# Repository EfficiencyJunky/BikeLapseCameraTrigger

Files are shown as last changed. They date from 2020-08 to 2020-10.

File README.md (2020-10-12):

# BikeLapseCameraTrigger Overview

The BikeLapse Camera Trigger is an Arduino based system for using distance (number of wheel rotations on a bike) to trigger a camera shutter release (as opposed to TimeLapse which uses time). It's part of a larger platform called BikeLapse.com that seeks to make it fun and easy to create a virtual catalog of bike rides (or other adventure activities). Plus it's entirely free and open source.

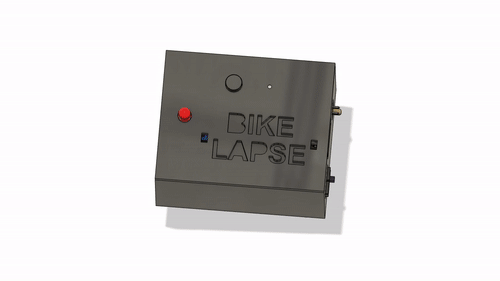
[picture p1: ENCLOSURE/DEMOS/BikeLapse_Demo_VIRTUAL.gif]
BikeLapse Hardware Virtual Demo


This repository is home to everything you should need to build your own BikeLapse Camera Trigger as seen in the animated GIF above and demo videos below. Once you've made the Camera Trigger hardware, visit the BikeLapse.com GitHub repo to learn how to clone the repo (you'll need to modify a couple things of course) and enable your own BikeLapse style website hosted for free on GitHub pages. (it should take less than an hour to get your own instance up and running thanks to the magic of Github).

# DEMOS
Here's a video showing how the BikeLapse camera trigger works and what it is used for
https://www.youtube.com/watch?v=APi-ftsqltU

Here's a demo of a video that was made by stitching together all of the images captured while using the BikeLapse Camera Trigger
https://www.youtube.com/watch?v=EekVvGeG3ls

To see the virtual bike ride version where the video is geo-synchronized to a map...check out https://bikelapse.com

# PROJECT DESCRIPTION AND BUILD INSTRUCTIONS
Visit http://turnerkirk.com/bikelapse for a thorough description of this project and information on how to make your own.

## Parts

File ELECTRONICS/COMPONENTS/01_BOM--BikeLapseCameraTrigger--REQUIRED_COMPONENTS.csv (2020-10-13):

Build Order | Customer Reference | Reference Designator | Quantity | Unit Price | Extended Price | Supplier | Supplier Part Number | Manufacturer | Manufacturer Part Number | Supplier Description | LINK | ALTERNATIVE LINK
0 | MAIN PCB | PCB1 | 1 | $7.77 | $7.77 | OshPark | chaYN0AE | OshPark | chaYN0AE | BikeLapse Camera Trigger MAIN BOARD - V1.3p24 | https://oshpark.com/shared_projects/chaYN0AE
1 | 210 Ohm Resistor for LED | R1 | 1 | $0.10 | $0.10 | Digi-Key | 210XBK-ND | Yageo | MFR-25FBF52-210R | RES 210 OHM 1/4W 1% AXIAL | https://www.digikey.com/en/products/detail/yageo/MFR-25FBF52-210R/12859
3 | Female Headers - Straight | various | 1 | $2.95 | $2.95 | Digi-Key | 1528-2537-ND | Adafruit Industries LLC | 598 | 36-PIN 0.1 FEMALE HEADER- 5PK | https://www.digikey.com/en/products/detail/adafruit-industries-llc/598/8299908 | https://www.adafruit.com/product/598
3 | male headers - Straight | various | 2 | $0.69 | $1.38 | Digi-Key | HDR100IMP40M-G-V-TH-ND | Chip Quik Inc. | HDR100IMP40M-G-V-TH | CONN HEADER VERT 40POS 2.54MM | https://www.digikey.com/en/products/detail/chip-quik-inc/HDR100IMP40M-G-V-TH/5978197
4 | Wheel Sensor (Reed Switch) Connector R/A Headers | S1 | 1 | $0.53 | $0.53 | Digi-Key | 732-2699-ND | Würth Elektronik | 61900211021 | CONN HEADER R/A 2POS 2.54MM | https://www.digikey.com/en/products/detail/w-rth-elektronik/61900211021/2508468
4 | Wheel Sensor (Reed Switch) Connector Housing | S1_external | 1 | $0.13 | $0.13 | Digi-Key | 732-2867-ND | Würth Elektronik | 61900211621 | CONN HSNG 2POS FEMALE 2.54MM | https://www.digikey.com/en/products/detail/w-rth-elektronik/61900211621/2508636
4 | Wheel Sensor (Reed Switch) Connector Receptacle Crimp Pins | S1_external | 3 | $0.10 | $0.30 | Digi-Key | S9473CT-ND | Sullins Connector Solutions | SWT25X-URTC-S01-UU-UU | CONN SOCKET 20-26AWG CRIMP TIN | https://www.digikey.com/en/products/detail/sullins-connector-solutions/SWT25X-URTC-S01-UU-UU/2769670
4 | Wheel Rotation Sensor (Reed Switch) w/ magnet | S1_external | 1 | $15.37 | $15.37 | Planet Bike | SKU #8000-3 | Planet Bike | SKU #8000-3 | PROTEGÉ TANDEM BRACKET - 160CM WIRE | https://www.planetbike.com/protege-tandem-bracket-160cm-wire/ | https://www.amazon.com/dp/B001CJVK9S/
4 | Arduino Bluetooth Brain Board -- NEW | U1 | 1 | $24.95 | $24.95 | Digi-Key | 1528-2828-ND | Adafruit Industries LLC | 4062 | ADAFRUIT FEATHER NRF52840 EXPRES | https://www.digikey.com/en/products/detail/adafruit-industries-llc/4062/9843410 | https://www.adafruit.com/product/4062
4 | BUTTONS PCB | U2_PCB2 | 1 | $1.08 | $1.08 | OshPark | NAQApft2 | OshPark | NAQApft2 | BikeLapse Camera Trigger BUTTON BOARD - V1.3p18 | https://oshpark.com/shared_projects/NAQApft2
4 | 12mm Button - CAMERA_TRIGGER | U2_B1 | 1 | $0.49 | $0.49 | Digi-Key | 430476085716-ND | Würth Elektronik | 430476085716 | SWITCH TACTILE SPST-NO 0.05A 12V | https://www.digikey.com/en/products/detail/w-rth-elektronik/430476085716/5209048
4 | 6mm Button - BLE_RESET | U2_B2 | 1 | $0.40 | $0.40 | Digi-Key | SW406-ND | Omron Electronics Inc-EMC Div | B3F-1070 | SWITCH TACTILE SPST-NO 0.05A 24V | https://www.digikey.com/en/products/detail/omron-electronics-inc-emc-div/B3F-1070/38362
5 | male headers - R/A | J1 | 1 | $0.79 | $0.79 | Digi-Key | HDR100IMP40M-G-RA-TH-ND | Chip Quik Inc. | HDR100IMP40M-G-RA-TH | CONN HEADER R/A 40POS 2.54MM | https://www.digikey.com/en/products/detail/chip-quik-inc/HDR100IMP40M-G-RA-TH/5978204
5 | On/Off Switch Straight | J1 | 1 | $0.65 | $0.65 | Digi-Key | EG1903-ND | E-Switch | EG1218 | SWITCH SLIDE SPDT 200MA 30V | https://www.digikey.com/en/products/detail/e-switch/EG1218/101726
5 | LED 5MM | LED1 | 1 | $0.35 | $0.35 | Digi-Key | 1125-1188-ND | Marktech Optoelectronics | MT4118-HR-A | LED RED DIFFUSED 5MM ROUND T/H | https://www.digikey.com/en/products/detail/marktech-optoelectronics/MT4118-HR-A/4214622
6 | Jumper Shorting Connectors | misc | 2 | $0.10 | $0.20 | Digi-Key | S9337-ND | Sullins Connector Solutions | QPC02SXGN-RC | CONN JUMPER SHORTING .100" GOLD | https://www.digikey.com/en/products/detail/sullins-connector-solutions/QPC02SXGN-RC/2618262
7 | M3 Screw w/ Phillips Head -- 8mm length | hardware | 2 | $0.05 | $4.57 | McMaster-Carr | 92010A118 | McMaster-Carr | 92010A118 | Passivated 18-8 Stainless Steel Phillips Flat Head Screw M3 x 0.5 mm Thread, 8 mm Long | https://www.mcmaster.com/92010A118/
7 | M3 Hex Lock Nut | hardware | 2 | $0.04 | $3.57 | McMaster-Carr | 90576A102 | McMaster-Carr | 90576A102 | Medium-Strength Steel Nylon-Insert Locknut Class 8, Zinc Plated, M3 x 0.5 mm Thread, 4 mm High | https://www.mcmaster.com/90576A102/
8 | 500mah Li-Ion Battery | power | 1 | $7.95 | $7.95 | Digi-Key | 1528-1841-ND | Adafruit Industries LLC | 1578 | BATTERY LITHIUM 3.7V 500MAH | https://www.digikey.com/en/products/detail/adafruit-industries-llc/1578/5054539 | https://www.adafruit.com/product/1578
9 | No6 Thread Cutting Screw w/ Phillips Head -- 1/4" Length | hardware | 4 | $0.05 | $5.02 | McMaster-Carr | 94629A180 | McMaster-Carr | 94629A180 | Thread-Cutting Screws for Plastic 410 Stainless Steel, Number 6 Size, 1/4" Long | https://www.mcmaster.com/94629A180/
9 | M4 Screw w/ Hex Socket Head | hardware | 1 | $0.09 | $9.22 | McMaster-Carr | 91290A148 | McMaster-Carr | 91290A148 | Black-Oxide Alloy Steel Socket Head Screw M4 x 0.7 mm Thread, 12 mm Long | https://www.mcmaster.com/91290A148/
9 | M4 Nut | hardware | 1 | $0.06 | $6.45 | McMaster-Carr | 91828A231 | McMaster-Carr | 91828A231 | 18-8 Stainless Steel Hex Nut M4 x 0.7 mm Thread | https://www.mcmaster.com/91828A231/

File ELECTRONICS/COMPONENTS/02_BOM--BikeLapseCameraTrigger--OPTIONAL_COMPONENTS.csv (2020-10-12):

Build Order | Customer Reference | Reference Designator | Quantity | Unit Price | Extended Price | Supplier | Supplier Part Number | Manufacturer | Manufacturer Part Number | Supplier Description | LINK | ALTERNATIVE LINK
1 (option) | 100k resistor (if using battery with thermistor) | R3 | 1 | $0.10 | $0.10 | Digi-Key | S100KCACT-ND | Stackpole Electronics Inc | RNMF14FTC100K | RES 100K OHM 1/4W 1% AXIAL | https://www.digikey.com/en/products/detail/stackpole-electronics-inc/RNMF14FTC100K/2617434
1 (option) | 120 Ohm Resistor (if using battery with thermistor AND Feather Huzzah ESP8266) | R5 | 1 | $0.10 | $0.10 | Digi-Key | S120CACT-ND | Stackpole Electronics Inc | RNMF14FTC120R | RES 120 OHM 1/4W 1% AXIAL | https://www.digikey.com/en/products/detail/stackpole-electronics-inc/RNMF14FTC120R/2617441
1 (option) | 270 Ohm Resistor (if using battery with thermistor AND Feather Huzzah ESP8266) | R4 | 1 | $0.10 | $0.10 | Digi-Key | S270CACT-ND | Stackpole Electronics Inc | RNMF14FTC270R | RES 270 OHM 1/4W 1% AXIAL | https://www.digikey.com/en/products/detail/stackpole-electronics-inc/RNMF14FTC270R/2617478
4 (option) | Arduino Bluetooth Brain Board -- OLD | U1 | 1 | $24.95 | $24.95 | Digi-Key | 1528-2095-ND | Adafruit Industries LLC | 3406 | FEATHER NRF52 BLUEFRUIT LE - NRF | https://www.digikey.com/en/products/detail/adafruit-industries-llc/3406/7034992 | https://www.adafruit.com/product/3406
5 (future) | On/Off Switch R/A (PCB design currently doesn't accomodate this part) | J1 | 1 | $1.09 | $1.09 | Digi-Key | 563-1555-ND | Nidec Copal Electronics | MFS101D-6-Z | SWITCH SLIDE SPDT 300MA 10V | https://www.digikey.com/en/products/detail/nidec-copal-electronics/MFS101D-6-Z/5086545
8 (alternative) | 1200mah Li-Ion Battery | power | 1 | $9.95 | $9.95 | Digi-Key | 1528-1838-ND | Adafruit Industries LLC | 258 | BATTERY LITHIUM 3.7V 1.2AH | https://www.digikey.com/en/products/detail/adafruit-industries-llc/258/5054544 | https://www.adafruit.com/product/258
8 (alternative) | 1000mah Li-Ion Battery | power | 1 | $9.95 | $9.95 | Digi-Key | 1568-1492-ND | SparkFun Electronics | PRT-13813 | BATTERY LITHIUM 3.7V 1AH | https://www.digikey.com/en/products/detail/sparkfun-electronics/PRT-13813/6605198 | https://www.sparkfun.com/products/13813

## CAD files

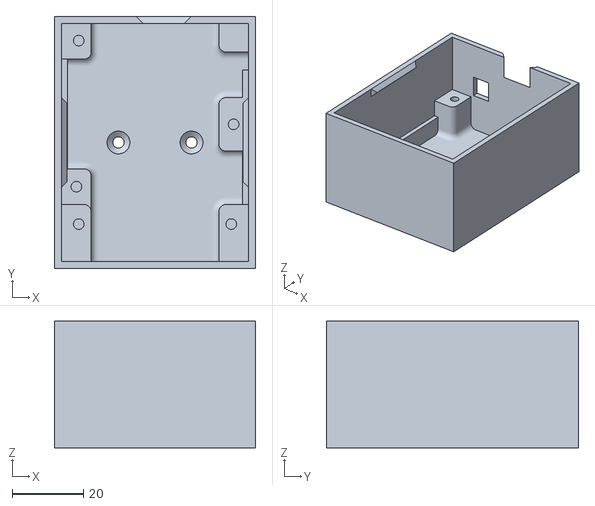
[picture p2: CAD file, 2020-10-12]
ENCLOSURE/3D_MODELS/COMPONENTS--V3p20/BikeLapseTrigger_Enclosure_V3p20--COMP-MAIN.stl
56.4 x 70.8 x 35.6

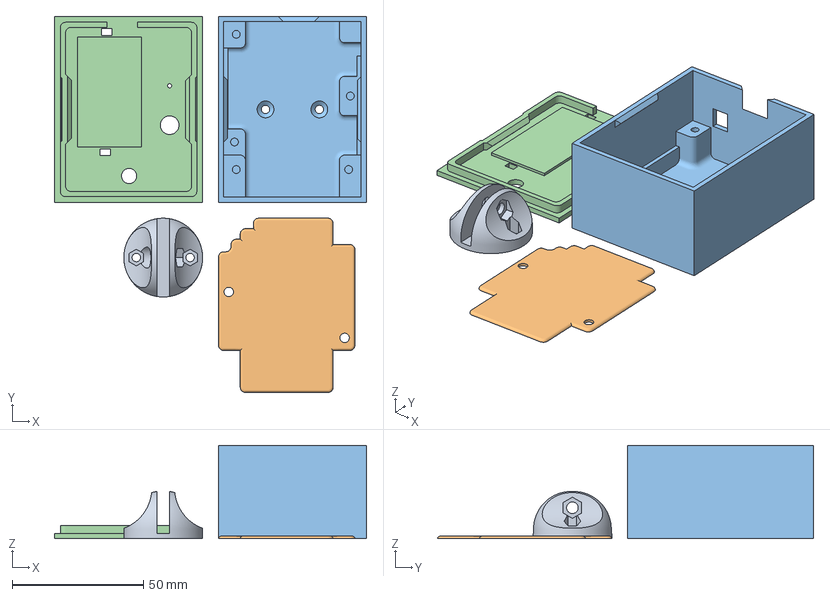
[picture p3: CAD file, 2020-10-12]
ENCLOSURE/3D_MODELS/BikeLapseTrigger_Enclosure_V3p20.3mf
118.8 x 143.2 x 35.6 mm
BikeLapseTrigger_V3p20--COMP-BASE.stl
BikeLapseTrigger_V3p20--COMP-BATT_COVER.stl
BikeLapseTrigger_V3p20--COMP-MAIN.stl
BikeLapseTrigger_V3p20--COMP-TOP.stl

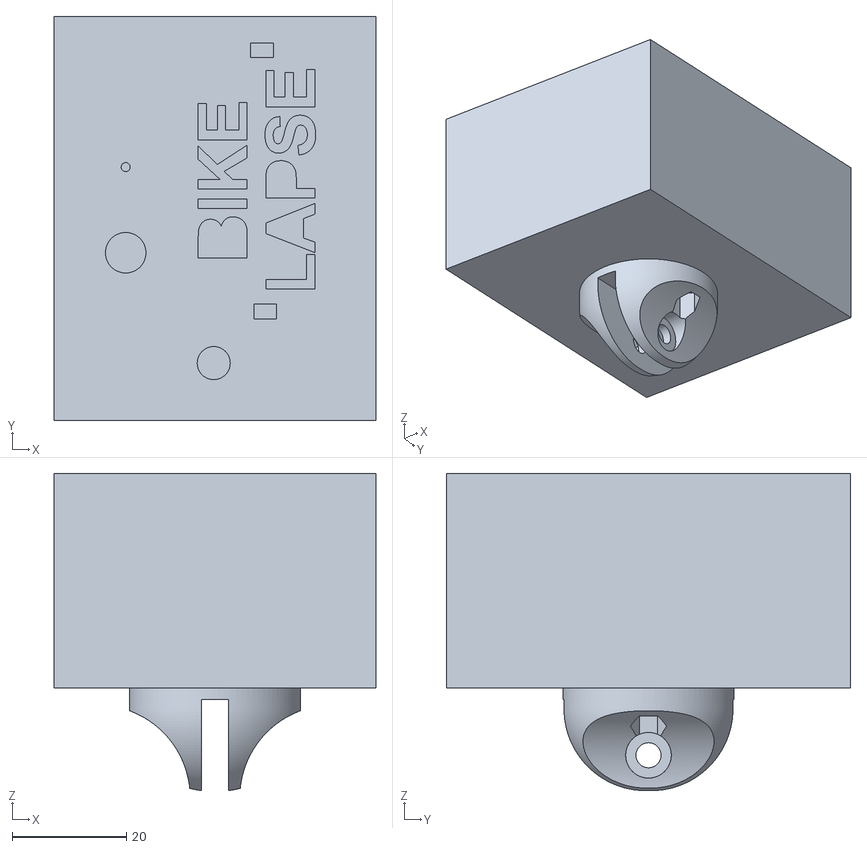
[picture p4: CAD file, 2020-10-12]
ENCLOSURE/3D_MODELS/BikeLapseTrigger_Enclosure_V3p20--SINGLE_FILE.stl
56.4 x 70.8 x 55.6

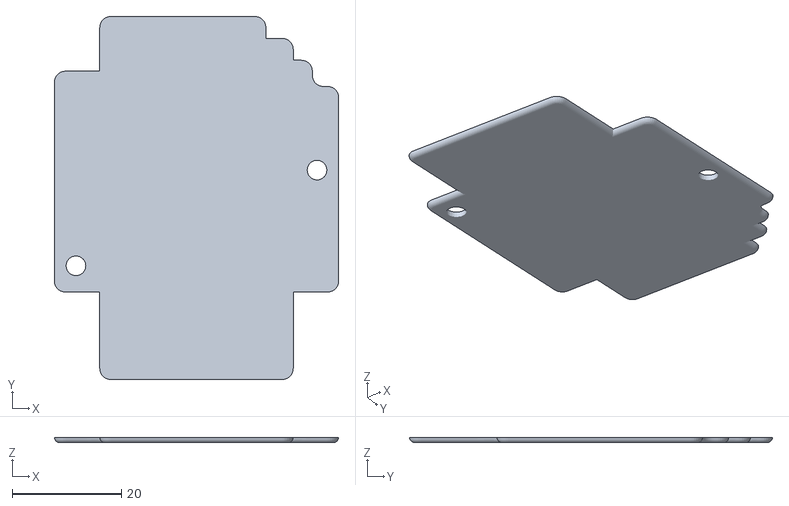
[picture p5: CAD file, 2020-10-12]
ENCLOSURE/3D_MODELS/COMPONENTS--V3p20/BikeLapseTrigger_Enclosure_V3p20--COMP-BATT_COVER.stl
52.0 x 66.4 x 1.00

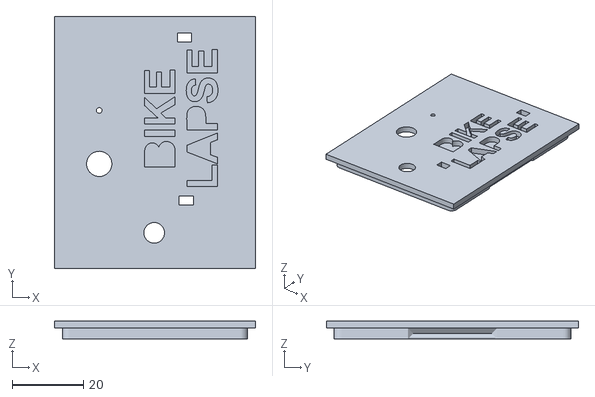
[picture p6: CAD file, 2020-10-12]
ENCLOSURE/3D_MODELS/COMPONENTS--V3p20/BikeLapseTrigger_Enclosure_V3p20--COMP-TOP.stl
56.4 x 70.8 x 5.00

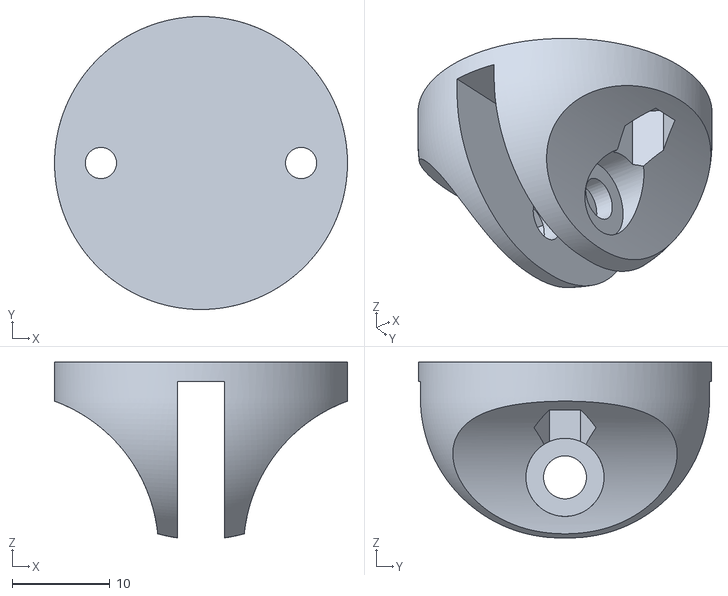
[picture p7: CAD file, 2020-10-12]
ENCLOSURE/3D_MODELS/COMPONENTS--V3p20/BikeLapseTrigger_Enclosure_V3p20--COMP-BASE.stl
30.0 x 30.0 x 18.0

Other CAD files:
ENCLOSURE/3D_MODELS/BikeLapseTrigger_Enclosure_V3p20--BUILD_PLATE.stl
ELECTRONICS/PCB/Button PCB for BikeLapse Camera Trigger v21.f3z

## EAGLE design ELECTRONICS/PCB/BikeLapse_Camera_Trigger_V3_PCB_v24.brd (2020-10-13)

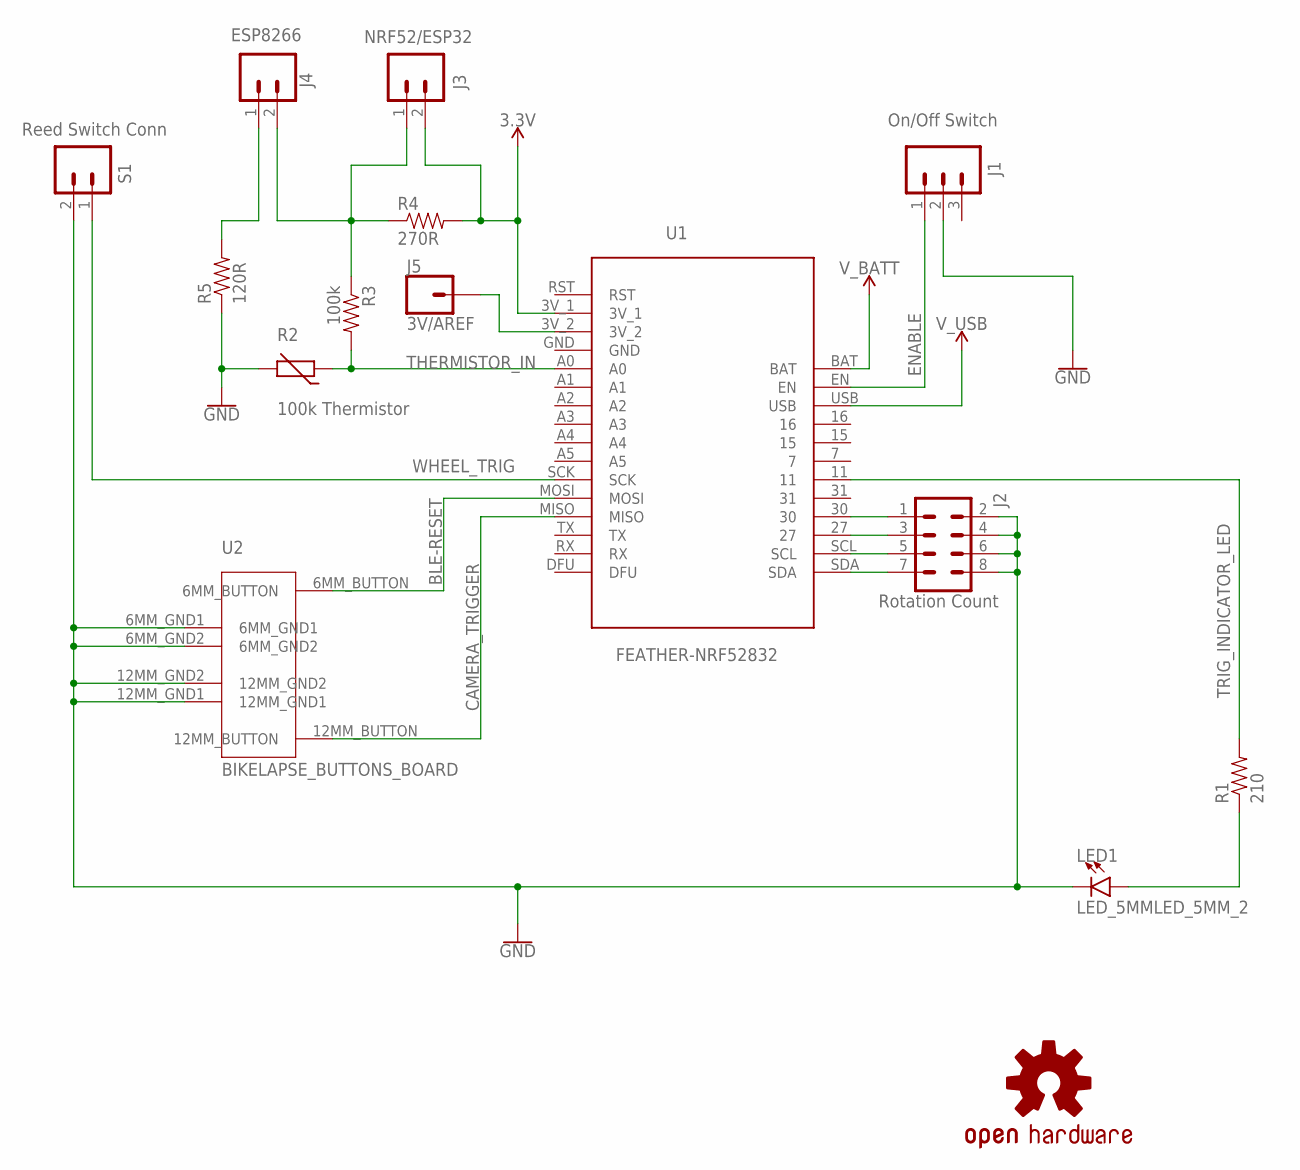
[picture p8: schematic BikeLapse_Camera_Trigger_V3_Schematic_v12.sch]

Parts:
J1: On/Off Switch; 1X03_RA_PTH
J2: Rotation Count; 2X4
J3: NRF52/ESP32; 1X02
J4: ESP8266; 1X02
J5: 3V/AREF; 1X01
LED1: LED_5MMLED_5MM_2; LEDRD254W60D565H860B
LOGO1: OSHW-LOGOL; OSHW-LOGO-L
R1: 210; SPARKFUN-RESISTORS_AXIAL-0.4
R2: 100k Thermistor; RS-2,5-SINGLE_PIN
R3: 100k; SPARKFUN-RESISTORS_AXIAL-0.4
R4: 270R; SPARKFUN-RESISTORS_AXIAL-0.4
R5: 120R; SPARKFUN-RESISTORS_AXIAL-0.4
S1: Reed Switch Conn; 1X02_RA_PTH
U1: FEATHER-NRF52832
U2: BIKELAPSE_BUTTONS_BOARD

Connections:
3.3V: J3.2, R4.P$2 (2), U1.3V_1
BLE-RESET: U1.MOSI, U2.6MM_BUTTON
CAMERA_TRIGGER: U1.MISO, U2.12MM_BUTTON
ENABLE: J1.1, U1.EN
GND: J1.2, J2.2, J2.4, J2.6, J2.8, LED1.K (C), R2.2, R5.P$1 (1), S1.2, U1.GND, U2.6MM_GND1, U2.6MM_GND2, U2.12MM_GND1, U2.12MM_GND2
unnamed: J2.3, U1.27
unnamed: J2.1, U1.30
unnamed: J2.5, U1.SCL
unnamed: J2.7, U1.SDA
unnamed: J5.1, U1.3V_2
unnamed: J4.1, R5.P$2 (2)
unnamed: J3.1, J4.2, R3.P$1 (1), R4.P$1 (1)
unnamed: LED1.A, R1.P$1 (1)
THERMISTOR_IN: R2.1, R3.P$2 (2), U1.A0
TRIG_INDICATOR_LED: R1.P$2 (2), U1.11
V_BATT: U1.BAT
V_USB: U1.USB
WHEEL_TRIG: S1.1, U1.SCK

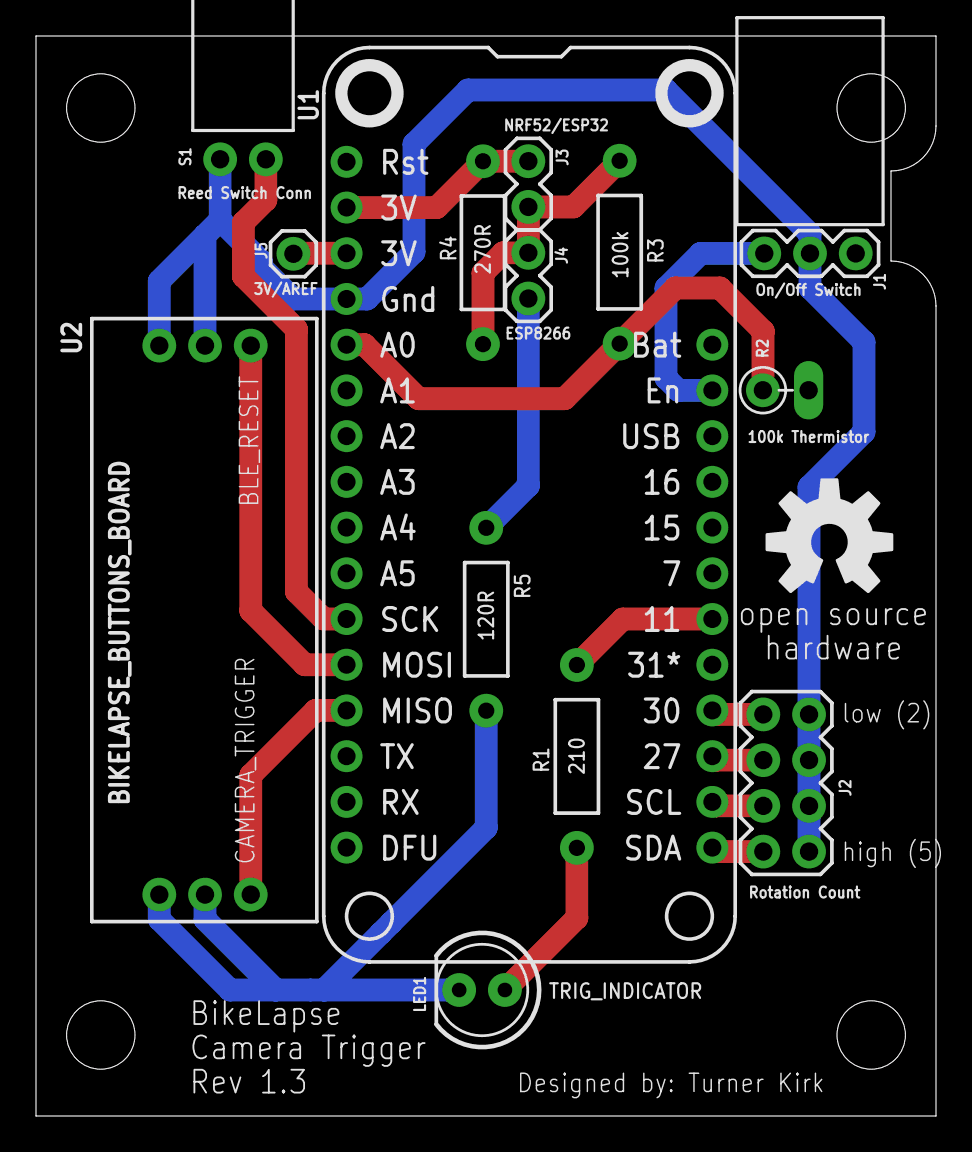
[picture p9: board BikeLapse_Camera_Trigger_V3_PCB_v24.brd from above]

Board: 2 copper layers, 50.0 x 60.0 mm, 15 parts (0 on the bottom side), 16 nets.

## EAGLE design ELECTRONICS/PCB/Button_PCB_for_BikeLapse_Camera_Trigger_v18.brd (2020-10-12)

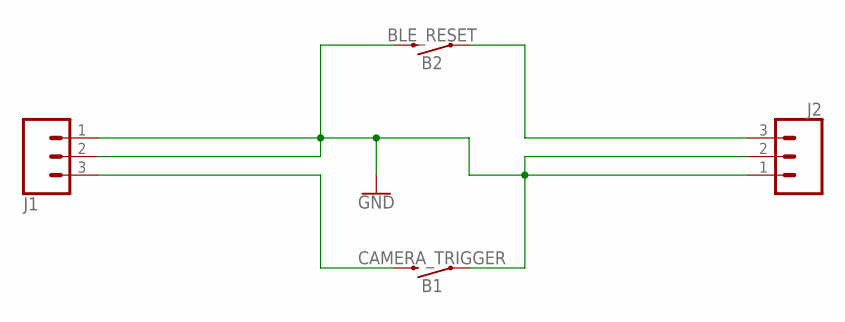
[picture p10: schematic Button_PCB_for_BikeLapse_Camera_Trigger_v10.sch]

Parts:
B1: CAMERA_TRIGGER; TACTILE_SWITCH_PTH_12MM
B2: BLE_RESET; TACTILE_SWITCH_PTH_6.0MM
J1, J2: 455-1750-1-ND; 1X03-MALE_HEADERS_BOTTOM

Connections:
GND: B1.1, B2.3 (2), J1.1, J1.2, J2.1, J2.2
unnamed: B2.1, J2.3
unnamed: B1.3 (2), J1.3

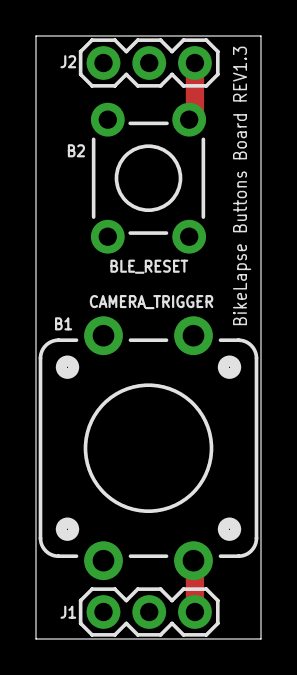
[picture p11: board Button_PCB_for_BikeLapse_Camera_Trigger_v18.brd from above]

Board: 2 copper layers, 12.5 x 33.5 mm, 4 parts (0 on the bottom side), 3 nets.

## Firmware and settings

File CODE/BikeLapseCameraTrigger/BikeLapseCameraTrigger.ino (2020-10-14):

/*
  Distance Lapse Camera Trigger for Bicycles
  Created April 2020 (during corona virius pandemic)

  Counts the number of wheel rotations on a bicycle and triggers a camera shutter release every Nth time
  the "N" number of rotations to trigger the shutter release can be set in the code or chosen via hardware jumpers

  The circuit:
  - LED attached from pin 13 to ground
  - Reed Switch attached to pin 10 from +5V


  Explain the rest of the circuit here:
  - 390 ohm resistor attached to pin 5 from the annode of an LED who's cathode is attached to ground

*/
// ************************************************
//        HARDWARE DECLARATIONS
// ************************************************
#define __FEATHER_NRF52840__
// #define __FEATHER_NRF52832__


// uncomment this #define to enable the serial monitor 
// we are using it only for testing the temperature readings from the thermistor
// when the BLE_RESET button is short pressed, the thermistor information will be printed to the serial monitor
// #define __SERIAL_MONITOR__

// ************************************************
//        LIBRARY INCLUDES
// ************************************************
#if defined(__FEATHER_NRF52832__) || defined(__FEATHER_NRF52840__)
  #include <bluefruit.h>
  BLEDis bledis;
  BLEHidAdafruit blehid;
//#elif defined(__FEATHER_ESP8266__)
//  #include <ESP8266WiFi.h>
#endif

// INFO ON THE BUTTON LIBRARY HERE: https://github.com/JChristensen/JC_Button
#include <JC_Button.h>
#include "BL_LEDControl.h"


// ************************************************
//        PIN AND HARDWARE DEFINITIONS
// ************************************************
#if defined(__FEATHER_NRF52840__)
  #define WHEEL_TRIGGER_PIN 26 // SCK
  #define SHUTTER_TRIGGER_PIN 24 // MISO
  #define BLE_RESET_PIN 25  // MOSI
  #define LED_PIN 10
  // #define LED_PIN LED_RED // onboard LED
  #define RESISTANCE_OFFSET 0
  #define SERIAL_BAUDRATE 115200
  // ************************************************
  //        JUMPER PIN VARIABLES
  // ************************************************
  #define SELECT_PIN_1 = 6; // Jumper for 2 rotations per trigger
  #define SELECT_PIN_2 = 5; // Jumper for 3 rotations per trigger
  #define SELECT_PIN_3 = SCL; // p0.11 Jumper for 4 rotations per trigger
  #define SELECT_PIN_4 = SDA; // p0.12 Jumper for 5 rotations per trigger
#elif defined(__FEATHER_NRF52832__)
  #define WHEEL_TRIGGER_PIN 12  // SCK
  #define SHUTTER_TRIGGER_PIN 14 // MISO
  #define BLE_RESET_PIN 13 // MOSI
  #define LED_PIN 11
  // #define LED_PIN LED_RED // onboard LED
  #define RESISTANCE_OFFSET 0
  #define SERIAL_BAUDRATE 115200
  // ************************************************
  //        JUMPER PIN VARIABLES
  // ************************************************
  #define SELECT_PIN_1 = 30; // Jumper for 2 rotations per trigger
  #define SELECT_PIN_2 = 27; // Jumper for 3 rotations per trigger
  #define SELECT_PIN_3 = SCL; // Jumper for 4 rotations per trigger
  #define SELECT_PIN_4 = SDA; // Jumper for 5 rotations per trigger
#endif



/*
 * 
 * The constructor defines a button object.
 * Syntax
 * Button(pin, dbTime, puEnable, invert);
 * 
 * Required parameter
 * pin: Arduino pin number that the button is connected to (byte)
 * 
 * Optional parameters
 * dbTime (unsigned long): Debounce time in milliseconds. Defaults to 25ms if not given. 
 * puEnable (bool) ( Defaults to true if not given): true to enable the microcontroller's internal pull-up resistor, else false. 
 * invert (bool) (Defaults to true if not given): 
 *         true should be used when a pull-up resistor is employed or puEnable=true. true interprets a low level as pressed. 
 *         false should be used when a pull-down resistor is being used or puEnable=false. false interprets a high logic level to mean the button is pressed, 
 */
// ************************************************
//        BUTTON LIBRARY VARIABLES
// ************************************************
#define PULLUP true    // these aren't required in the most recent version of JC_Button because they are defaults when using a button that is set up to be pulled low
#define INVERT true    // these aren't required in the most recent version of JC_Button because they are defaults when using a button that is set up to be pulled low
#define DEBOUNCE_MS   40       // sets the debounce time in ms. Should be between 20-50 ms depending on the button
#define LONG_PRESS 1000    //We define a "long press" to be 1000 milliseconds.

Button wheelTriggerButton(WHEEL_TRIGGER_PIN, DEBOUNCE_MS);    //Declare the button (this also initializes the pin it's attached to)
Button shutterTriggerButton(SHUTTER_TRIGGER_PIN, DEBOUNCE_MS);    //Declare the button (this also initializes the pin it's attached to)
Button bluetoothResetButton(BLE_RESET_PIN, DEBOUNCE_MS);    //Declare the button (this also initializes the pin it's attached to)


// ************************************************
//        BUTTON STATE LOGIC VARIABLES
// ************************************************
enum states_t {NORMAL, LONGPRESS, CANCEL_LONGPRESS};
states_t SHUTTER_TRIGGER_STATE = NORMAL;      // current state machine state
states_t BLE_RESET_STATE = NORMAL;      // current state machine state

unsigned long longPressTimeoutStartTime = 0;
unsigned long longPressTimeoutInterval = 4000;


// ************************************************
//        WHEEL TRIGGER LOGIC VARIABLES
// ************************************************
int wheelRotationCounter = 0;   // counter for the number of button presses
int numRotationsToTrigger = 4;  // the default number of rotations it takes to trigger the camera
bool wheelTriggerActive = true;


// ************************************************
//        LED PIN AND CONTROL CLASS VARIABLES
// ************************************************
BL_LEDControl ledController(LED_PIN);


// ************************************************
//        THERMISTOR VARIABLES
// ************************************************
// Thermistor Example #3 from the Adafruit Learning System guide on Thermistors 
// https://learn.adafruit.com/thermistor/overview by Limor Fried, Adafruit Industries
// MIT License - please keep attribution and consider buying parts from Adafruit

// What pin to connect the sensor to
#define THERMISTORPIN A0
//const int thermistorPin = A0;  // the pin that the thermistor reading is taken from
// resistance at 25 degrees C -- set this to the value in your thermistor's datasheet
#define THERMISTORNOMINAL 100000      
// temp. for nominal resistance (datasheets almost always say 25 C (or 77 F) ) -- To convert Celsius to Farenheight, Multiply by 1.8 (or 9/5) and add 32.
//#define TEMPERATURENOMINAL 25
#define TEMPERATURENOMINAL 22.22   // decided to go with actual room temperature 22.2 C (or 72 F) because it seemed more accurate in actual testing
// how many samples to take and average, more takes longer
// but is more 'smooth'
#define NUMSAMPLES 5
// The beta coefficient of the thermistor (usually 3000-4000)
#define BCOEFFICIENT 3950
// the value of the 'other' resistor which can be any value but to make things easy just make it as close to the 
// nominal value of the thermistor. Make sure to measure the ACTUAL value of your resistor and put it's actual value here
#define SERIESRESISTOR 100000
// #define SERIESRESISTOR 93600  // this is a different value for a series resistor that isn't quite 100k

int thermistorValue = 0;  // variable to store the value coming from the sensor
bool displayThermistor = false;




// ************************************************
//        SETUP FUNCTION 
//        SETUP FUNCTION 
//        SETUP FUNCTION 
// ************************************************
void setup() {

  // initialize the LED as an output:
  pinMode(LED_PIN, OUTPUT);

  wheelTriggerButton.begin();
  shutterTriggerButton.begin();
  bluetoothResetButton.begin();


  // UNCOMMENT THE FOLLOWING CODE TO ENABLE SETTING THE NUMBER OF WHEEL ROTATIONS FOR TRIGGERING THE CAMERA  
  // initialize the selectPins as inputs:
//  pinMode(SELECT_PIN_1, INPUT_PULLUP);
//  pinMode(SELECT_PIN_2, INPUT_PULLUP);
//  pinMode(SELECT_PIN_3, INPUT_PULLUP);
//  pinMode(SELECT_PIN_4, INPUT_PULLUP);


//  if(digitalRead(SELECT_PIN_1) == LOW){
//    numRotationsToTrigger = 2;
//  }
//  else if(digitalRead(SELECT_PIN_2) == LOW){
//    numRotationsToTrigger = 3;
//  }
//  else if(digitalRead(SELECT_PIN_3) == LOW){
//    numRotationsToTrigger = 4;
//  }  
//  else if(digitalRead(SELECT_PIN_4) == LOW){
//    numRotationsToTrigger = 5;
//  }
//  else{
//    numRotationsToTrigger = 4;
//  }


//  pinMode(THERMISTORPIN, INPUT); // don't actually need to specify this because it's an Analog pin

// THIS IS FOR THE THERMISTOR READINGS TO DISPLAY IN THE SERIAL MONITOR
#if defined(__SERIAL_MONITOR__)
  Serial.begin(SERIAL_BAUDRATE);       // use the serial port at the baudrate defined by the hardware
  
  #if defined(__FEATHER_NRF52832__)
    while ( !Serial ) delay(10);   // for nrf52832 without native usb
  #endif
#endif


  // INITIALIZE ALL OF THE BLUETOOTH HARDWARE
  Bluefruit.begin();
  Bluefruit.setTxPower(4);    // Check bluefruit.h for supported values
  Bluefruit.setName("Bluefruit52"); // sets the name of the device that shows up on your phone's Bluetooth list

  // Configure and start DIS (Device Information Service)
  bledis.setManufacturer("Adafruit Industries");
  bledis.setModel("Bluefruit Feather 52");
  bledis.begin();

  /* Start BLE HID
   * Note: Apple requires BLE devices to have a min connection interval >= 20m
   * (The smaller the connection interval the faster we can send data).
   * However, for HID and MIDI device Apple will accept a min connection
   * interval as low as 11.25 ms. Therefore BLEHidAdafruit::begin() will try to
   * set the min and max connection interval to 11.25 ms and 15 ms respectively
   * for the best performance.
   */
  blehid.begin();

  /* Set connection interval (min, max) to your perferred value.
   * Note: It is already set by BLEHidAdafruit::begin() to 11.25ms - 15ms
   * min = 9*1.25=11.25 ms, max = 12*1.25= 15 ms
   */
  /* Bluefruit.Periph.setConnInterval(9, 12); */

  // Set up and start advertising
  startAdv();


}

void startAdv(void)
{
  // Advertising packet
  Bluefruit.Advertising.addFlags(BLE_GAP_ADV_FLAGS_LE_ONLY_GENERAL_DISC_MODE);
  Bluefruit.Advertising.addTxPower();
  Bluefruit.Advertising.addAppearance(BLE_APPEARANCE_HID_KEYBOARD);

  // Include BLE HID service
  Bluefruit.Advertising.addService(blehid);

  // There is enough room for the dev name in the advertising packet
  Bluefruit.Advertising.addName();
  
  /* Start Advertising
   * - Enable auto advertising if disconnected
   * - Interval:  fast mode = 20 ms, slow mode = 152.5 ms
   * - Timeout for fast mode is 30 seconds
   * - Start(timeout) with timeout = 0 will advertise forever (until connected)
   * 
   * For recommended advertising interval
   * https://developer.apple.com/library/content/qa/qa1931/_index.html   
   */
  Bluefruit.Advertising.restartOnDisconnect(true);
  Bluefruit.Advertising.setInterval(32, 244);    // in unit of 0.625 ms
  Bluefruit.Advertising.setFastTimeout(30);      // number of seconds in fast mode
  Bluefruit.Advertising.start(0);                // 0 = Don't stop advertising after n seconds  
}

// ************************************************
//        MAIN LOOP 
//        MAIN LOOP 
//        MAIN LOOP 
// ************************************************
void loop() {

  //Read the buttons
  wheelTriggerButton.read();   
  shutterTriggerButton.read();
  bluetoothResetButton.read();

  /*----------------------------------------------------------------------*
  / wheelTriggerButton Logic:
  /   If the wheel completed a rotation and wheelTriggerActive is "true", 
  /   update the LED classes state
  /-----------------------------------------------------------------------*/
  if (wheelTriggerButton.wasPressed() && wheelTriggerActive) {
    wheelRotationCounter++;
    // turns on the LED every four wheel rotationsby checking the modulo of the
    // wheelRotationCounter. the modulo function gives you the remainder of the
    // division of two numbers:
    if (wheelRotationCounter % numRotationsToTrigger == 0)
    {
      ledController.turnOn();
      sendShutterReleaseCommand();
    }
    else
    {
      ledController.turnOff();
    }
  }

  // run the logic for our buttons
  updateShutterTriggerButtonLogic();
  updateBluetoothResetButtonLogic();

  // Update the LED based on the logic set by the wheel trigger and buttons
  ledController.Update();

}


/*----------------------------------------------------------------------*
/ shutterTriggerButton Logic:
/   If the button was released, flash the led as an indicator
/   If the button was long pressed:
/       disconnect/connect the wheel trigger
/       set the LED into a pulsing or off state
/       invert the on/off logic for the LED when this button is short-pressed again
/-----------------------------------------------------------------------*/
void updateShutterTriggerButtonLogic(){
  switch (SHUTTER_TRIGGER_STATE){
    // this state watches for short and long presses, triggers the LED for
    // short presses, and moves to the LONGPRESS state for long presses.
    // for short presses it sets the logic based on if the wheel trigger is active
    case NORMAL:
      if (shutterTriggerButton.wasReleased()){
        ledController.turnOnOff(wheelTriggerActive);
        sendShutterReleaseCommand();
      }
      else if (shutterTriggerButton.pressedFor(LONG_PRESS)){
        longPressTimeoutStartTime = millis();
        SHUTTER_TRIGGER_STATE = LONGPRESS;
      }
      break;

    // this is a transition state where we are waiting for the user to release the button.
    // If they take too long to release the button, we move to the CANCEL_LONGPRESS state
    // If they release the button within the longPressTimeoutInterval, we do a few things:
    //    Set the LED to its pulsing or non pulsing state (depending on if wheelTriggerActive)
    //    Enable or disable the wheelTriggerActive boolean
    //    move back to the NORMAL state
    case LONGPRESS:
      if(millis() - longPressTimeoutStartTime > longPressTimeoutInterval){
        SHUTTER_TRIGGER_STATE = CANCEL_LONGPRESS;
      }
      else{
        if (shutterTriggerButton.wasReleased()){
          ledController.pulse(wheelTriggerActive);

          wheelTriggerActive = !wheelTriggerActive;

          SHUTTER_TRIGGER_STATE = NORMAL;
        }
      }
      break;

    // this is a transition state where we just wait for the user to release the button
    // before moving back to the NORMAL state. Once the button is released we need to 
    // set the led to be pulsing and invert the logic for subsequent button presses
    case CANCEL_LONGPRESS:
      if (shutterTriggerButton.wasReleased()){
          SHUTTER_TRIGGER_STATE = NORMAL;
      }
      break;      
  }
}


/*----------------------------------------------------------------------*
/ bluetoothResetButton Logic:
/   If the button was released, flash the led as an indicator
/   If the button was long pressed:
/       disconnect/connect the wheel trigger
/       set the LED into a pulsing or off state
/       invert the on/off logic for the LED when this button is short-pressed again
/-----------------------------------------------------------------------*/
void updateBluetoothResetButtonLogic(){

  switch (BLE_RESET_STATE){
    // this state watches for short and long presses, triggers the LED for
    // short presses, and moves to the LONGPRESS state for long presses.
    // for short presses it sets the logic based on if the wheel trigger is active
    case NORMAL:
      if (bluetoothResetButton.wasReleased()){
        readAndReactToTemperature();
      }
      else if (bluetoothResetButton.pressedFor(LONG_PRESS)){
        longPressTimeoutStartTime = millis();
        BLE_RESET_STATE = LONGPRESS;
      }
      break;

    // this is a transition state where we are waiting for the user to release the button.
    // If they take too long to release the button, we move to the CANCEL_LONGPRESS state
    // If they release the button within the longPressTimeoutInterval, we 
    // reset the bluetooth credentials and flash the LED as 
    case LONGPRESS:
      if(millis() - longPressTimeoutStartTime > longPressTimeoutInterval){
        BLE_RESET_STATE = CANCEL_LONGPRESS;
      }
      else{
        if (bluetoothResetButton.wasReleased()){
          resetBluetoothCredentials();
          BLE_RESET_STATE = NORMAL;
        }
      }
      break;

    // this is a transition state where we just wait for the user to release the button
    // before moving back to the NORMAL state. 
    case CANCEL_LONGPRESS:
      if (bluetoothResetButton.wasReleased()){
          BLE_RESET_STATE = NORMAL;
      }
      break;      
  }
}


void resetBluetoothCredentials(){

  // digitalWrite(LED_PIN, LOW);
  analogWrite(LED_PIN, 0);
  delay(100);

  for(uint8_t i = 0; i < 15; i++){
    // digitalWrite(LED_PIN, HIGH);
    analogWrite(LED_PIN, 255);
    delay(50);
    // digitalWrite(LED_PIN, LOW);
    analogWrite(LED_PIN, 0);
    delay(50);
  }
}




void sendShutterReleaseCommand(){
  // Make sure we are connected and bonded/paired
  for (uint16_t conn_hdl=0; conn_hdl < BLE_MAX_CONNECTION; conn_hdl++)
  {
    BLEConnection* connection = Bluefruit.Connection(conn_hdl);

    if ( connection && connection->connected() && connection->paired() )
    {
      // Turn on red LED when we start sending data
      // digitalWrite(LED_RED, 1);
      analogWrite(LED_RED, 255);

      // Send the 'volume down' key press to the peer
      // Check tinyusb/src/class/hid/hid.h for a list of valid consumer usage codes
      blehid.consumerKeyPress(conn_hdl, HID_USAGE_CONSUMER_VOLUME_DECREMENT);

      // Delay a bit between reports
      delay(10);

      // Send key release
      blehid.consumerKeyRelease(conn_hdl);

      // Turn off the red LED
      // digitalWrite(LED_RED, 0);
      analogWrite(LED_RED, 0);
    }
  }
}







void readAndReactToTemperature(){

  float reading;
 
  reading = analogRead(THERMISTORPIN);
 
 #if defined(__SERIAL_MONITOR__) 
  Serial.print("Analog reading "); 
  Serial.println(reading);
 #endif

  // convert the value to resistance
  reading = (1023 / reading)  - 1;     // (1023/ADC - 1) 
  reading = SERIESRESISTOR / reading + RESISTANCE_OFFSET;  // 100K / (1023/ADC - 1)
  // Serial.print("Thermistor resistance "); 
  // Serial.println(reading);

  float steinhart;
  steinhart = reading / THERMISTORNOMINAL;     // (R/Ro)
  steinhart = log(steinhart);                  // ln(R/Ro)
  steinhart /= BCOEFFICIENT;                   // 1/B * ln(R/Ro)
  steinhart += 1.0 / (TEMPERATURENOMINAL + 273.15); // + (1/To)
  steinhart = 1.0 / steinhart;                 // Invert
  steinhart -= 273.15;                         // convert to C
  
#if defined(__SERIAL_MONITOR__)  
  Serial.print("Thermistor resistance "); 
  Serial.println(reading);

  Serial.print("Temperature "); 
  Serial.print(steinhart);
  Serial.println(" *C");

  Serial.print("Temperature "); 
  Serial.print(steinhart * 1.8 + 32);
  Serial.println(" *F");
#endif

}

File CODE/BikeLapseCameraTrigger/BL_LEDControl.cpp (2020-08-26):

#include "BL_LEDControl.h"

// ******************************************************************    
//                 LED Controller CLASS
//    This class manages the state of the led based
//    on the input from the buttons
//    It uses software timers to ensure that it doesn't 
//    block the main thread
// ******************************************************************


// ******************************************************************    
//                         UPDATE METHOD
// ******************************************************************  
void BL_LEDControl::Update() {

    switch (STATE) {
        // inactive state so we aren't constantly writing to the LED pin
        case INACTIVE:
        break;
        
        // turn the LED ON
        case LED_ON:
            // digitalWrite(ledPin, HIGH);
            analogWrite(ledPin, highBrightness);
            STATE = INACTIVE;
            break;
        
        // turn the LED OFF
        case LED_OFF:
            // digitalWrite(ledPin, LOW);
            analogWrite(ledPin, 0);
            STATE = INACTIVE;
            break;
        
        // turn the LED ON and then OFF after "ledOnOffInterval" milliseconds
        case LED_ON_OFF:
            // digitalWrite(ledPin, HIGH);
            analogWrite(ledPin, highBrightness);
            if( (millis() - ledOnOffStartTime) > ledOnOffInterval){
                STATE = LED_OFF;
            }
            break;
        
        // turn the LED OFF and then back to PULSE after "ledOnOffInterval" milliseconds
        case LED_OFF_PULSE: 
            // digitalWrite(ledPin, LOW);
            analogWrite(ledPin, 0);
            if( (millis() - ledOnOffStartTime) > ledOnOffInterval){
                STATE = LED_PULSE;
            }
            break;

        // slowly pulse the led brightness
        case LED_PULSE:
            if( (millis() - lastPulseUpdateTime) > pulseUpdateInterval){
                analogWrite(ledPin, brightness);

                // change the brightness for next time through the loop:
                brightness = brightness + fadeAmount;

                // reverse the direction of the fading at the ends of the fade:
                if (brightness <= lowBrightness || brightness >= highBrightness) {
                    fadeAmount = -fadeAmount;
                }

                lastPulseUpdateTime = millis();
            }
            break;

    //      default:
    //        break;

    }

}

/*----------------------------------------------------------------------*
/ Set the state to LED_ON                                               *
/-----------------------------------------------------------------------*/
void BL_LEDControl::turnOn() {
    STATE = LED_ON;
}

/*----------------------------------------------------------------------*
/ Set the state to LED_OFF                                              *
/-----------------------------------------------------------------------*/
void BL_LEDControl::turnOff() {
    STATE = LED_OFF;
}

/*----------------------------------------------------------------------*
/ Set the state to LED_ON_ON or LED_ON_OFF depending on if the input    *
/ is inverted and record the time this occured                          *
/-----------------------------------------------------------------------*/
void BL_LEDControl::turnOnOff(bool normalState) {
    if(normalState) {
        STATE = LED_ON_OFF;
    }
    else {
        STATE = LED_OFF_PULSE;
    }

    ledOnOffStartTime = millis();
}

/*----------------------------------------------------------------------*
/ Set the state to LED_PULSE                                            *
/-----------------------------------------------------------------------*/
void BL_LEDControl::pulse(bool normalState) {
    
    if(normalState) {
        STATE = LED_PULSE;
    }
    else {
        STATE = LED_OFF;
    }    
    
}

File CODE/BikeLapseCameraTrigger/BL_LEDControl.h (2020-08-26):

/*
  DL_LED_Controller.h     - Class that provides control of an LED indicator for TK's Distance Lapse Camera Trigger
                                s
  Created by Turner E. Kirk, April 20, 2020.
  Released into the public domain.
*/

#ifndef BL_LEDControl_h
#define BL_LEDControl_h

// ******************************************************************
//            Includes and Defines
// ******************************************************************
#include <Arduino.h>

// ******************************************************************    
//                 LED Controller CLASS
//    This class manages the state of the led based
//    on the input from the buttons
//    It uses software timers to ensure that it doesn't 
//    block the main thread
// ******************************************************************
class BL_LEDControl
{

  private:
    // ENUM TO KEEP TRACK OF VARIOUS STATES
    enum {INACTIVE, LED_ON, LED_OFF, LED_ON_OFF, LED_OFF_PULSE, LED_PULSE};
    
    const uint8_t ledPin;
    uint8_t STATE = LED_OFF;

    unsigned long ledOnOffStartTime = 0;   // the time when the LED was turned on for the LED_ON_OFF or LED_OFF_ON cycle
    unsigned long ledOnOffInterval = 500;   // milliseconds the led will turn on then off (or off then on)
    
    unsigned long lastPulseUpdateTime = 0;   // milliseconds the pulse will update
    unsigned long pulseUpdateInterval = 20;   // milliseconds the pulse will update
    
    uint8_t brightness = 10;    // how bright the LED is
    uint8_t fadeAmount = 5;    // how many points to fade the LED by
    uint8_t lowBrightness = 10;
    uint8_t highBrightness = 150;

  public: 
  // ******************************************************************    
  //                         CONSTRUCTOR                     
  // ******************************************************************
    BL_LEDControl(const uint8_t _ledPin) : ledPin(_ledPin){}

  // ******************************************************************    
  //                         PUBLIC METHODS
  // ******************************************************************  
  void Update();
  void turnOn();
  void turnOff();
  void turnOnOff(bool normalState);
  void pulse(bool normalState);

};


#endif

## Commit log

2020-04-26 First Iteration of basic button logic complete
2020-04-28 updated LED communication to use only analogWrite and made final tweaks
2020-04-28 fixed bug where ledPin was used instead of LED_PIN in main .ino sketch
    [DistanceLapseCameraTrigger.ino]
2020-10-12 Finished V3 version ready for ordering and building
    [BikeLapseTrigger_Enclosure_V3p20--BUILD_PLATE.stl, BikeLapseTrigger_Enclosure_V3p20--COMP-BASE.stl, BikeLapseTrigger_Enclosure_V3p20--COMP-BATT_COVER.stl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]
2020-10-12 added BOM and PCB files
    [01_BOM--BikeLapseCameraTrigger--REQUIRED_COMPONENTS.csv, 02_BOM--BikeLapseCameraTrigger--OPTIONAL_COMPONENTS.csv, BikeLapse_Camera_Trigger_V3_PCB_v20.brd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]
2020-10-13 updated BRD to have notch for battery wires
    [01_BOM--BikeLapseCameraTrigger--REQUIRED_COMPONENTS.csv, BikeLapse_Camera_Trigger_V3_PCB_v20.brd, BikeLapse_Camera_Trigger_V3_PCB_v23.brd]
2020-10-13 updated PCB to have separate 3V/Aref pin
    [01_BOM--BikeLapseCameraTrigger--REQUIRED_COMPONENTS.csv, BikeLapse_Camera_Trigger_V3_PCB_v23.brd, BikeLapse_Camera_Trigger_V3_PCB_v24.brd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]
2020-10-14 updated BikeLapseCameraTrigger.ino to work with both nRF52 feather boards
